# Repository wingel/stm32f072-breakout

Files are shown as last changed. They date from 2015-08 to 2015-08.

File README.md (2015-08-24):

STM32F072 Breakout Board
========================

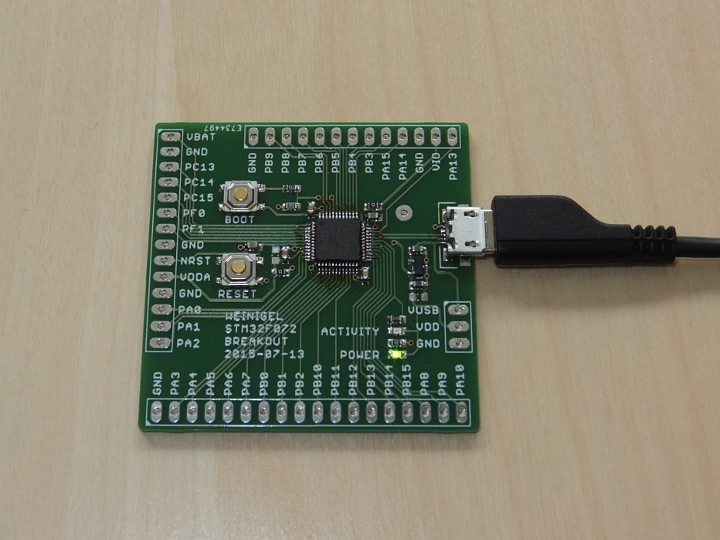
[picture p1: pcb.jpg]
Mounted PCB


This is a small breakout board for the STM32F072 MCU in a LQFP48
package.  I wanted something that would make it easier to try things
out with a small STM2F07 MCU and this PCB is the result.  This PCB
should also work with the STM32F042 MCU and maybe even other STM MCUs
in the same package, but I have not tested that.

Features
--------

* A Micro USB for powering the board and communicating with a host

* All other I/O pins are routed to a 2.54mm pin header

* A voltage regulator which provides VDD

* VIO and VDDA are normally provided from VDD via 0Ω resistors, but
  can optionally be provided externally via a pin header

* RESET and BOOT buttons

* A power LED which shows when the PCB is powered

* A user programmable LED which is connected to I/O pin PA10 (optional)

* PCB is 2 layers and smaller than 50x50mm and so ordering from China
  will only cost about $10 + shipping for 10 PCBs.

Firmware
========

A firmware based on [ChibiOS-RT](http://www.chibios.org/) can be found
on [GitHub](https://github.com/wingel/chibios-stm).

License
=======

[stm32f072-breakout](https://github.com/wingel/stm32f072-breakout) by
[Christer Weinigel](mailto:christer@weinigel.se) is licensed under a
[Creative Commons Attribution 4.0 International
License](http://creativecommons.org/licenses/by/4.0/).



The intent is to make this PCB available to anyone that finds it
useful as long as I get credit for the original design.  If you want
to use the design and have issues with the above license, please
contact me.

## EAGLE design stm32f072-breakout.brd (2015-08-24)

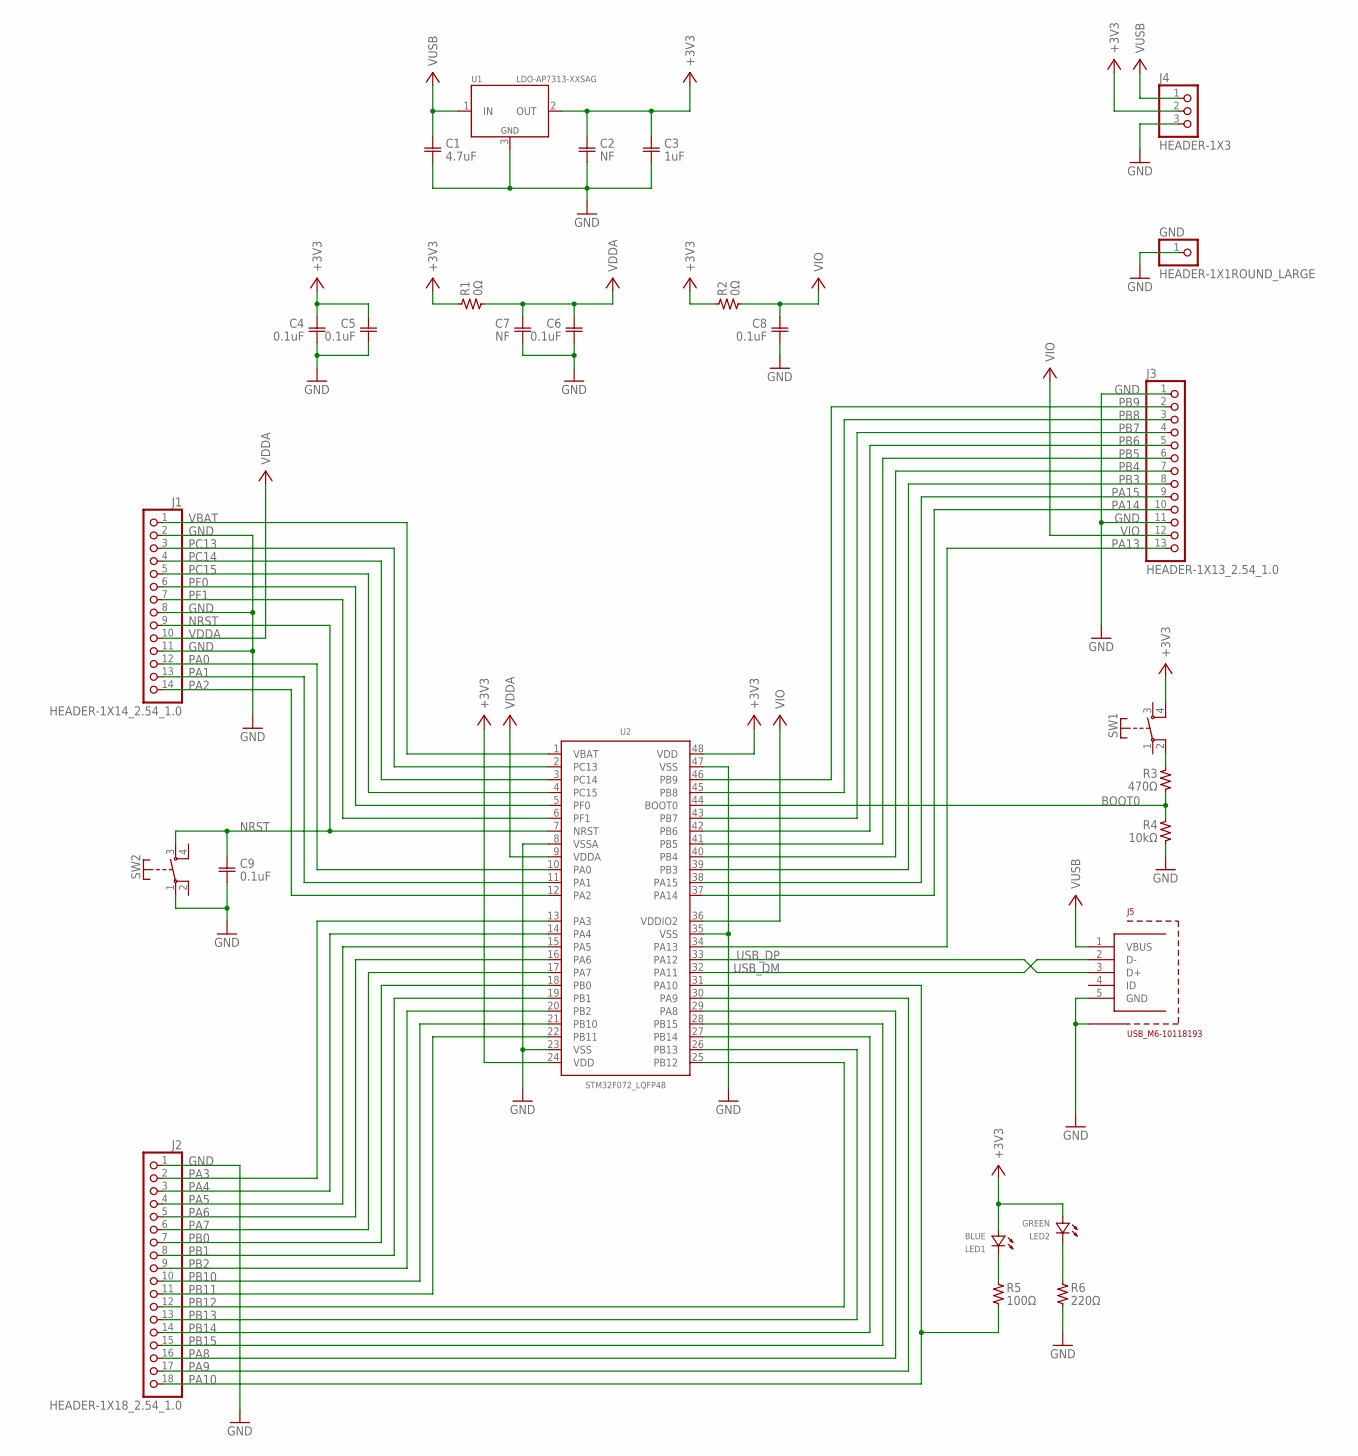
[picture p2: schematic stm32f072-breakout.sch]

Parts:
C1: 4.7uF; 0603
C2, C7: NF; 0603
C3: 1uF; 0603
C4, C5, C6, C8, C9: 0.1uF; 0603
GND: HEADER-1X1ROUND_LARGE; 1X01_ROUND_LARGE
J1: HEADER-1X14_2.54_1.0; 1X14_OVAL
J2: HEADER-1X18_2.54_1.0; 1X18_OVAL
J3: HEADER-1X13_2.54_1.0; 1X13_OVAL
J4: HEADER-1X3; 1X03_OVAL
J5: USB_M6-10118193; FCI-10118193
LED1: BLUE; 0603-POL
LED2: GREEN; 0603-POL
R1, R2: 0Ω; 0603
R3: 470Ω; 0603
R4: 10kΩ; 0603
R5: 100Ω; 0603
R6: 220Ω; 0603
SW1, SW2: SWITCH_OFF(ON)_2-MJTP1140A; MJTP1140A
U1: LDO-AP7313-XXSAG; SOT23
U2: STM32F072_LQFP48; LQFP48

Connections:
+3V3: C2.1, C3.1, C4.1, C5.1, J4.2, LED1.2 (A), LED2.2 (A), R1.1, R2.1, SW1.4, U1.2 (OUT), U2.24 (VDD), U2.48 (VDD)
BOOT0: R3.2, R4.1, U2.44 (BOOT0)
GND: C1.2, C2.2, C3.2, C4.2, C5.2, C6.2, C7.2, C8.2, C9.2, GND.1, J1.2, J1.8, J1.11, J2.1, J3.1, J3.11, J4.3, J5.5 (GND), J5.SHIELD@1 (SHIELD), J5.SHIELD@2 (SHIELD), J5.SHIELD@3 (SHIELD), J5.SHIELD@4 (SHIELD), J5.SHIELD@5 (SHIELD), J5.SHIELD@6 (SHIELD), J5.SHIELD@7 (SHIELD), J5.SHIELD@8 (SHIELD), R4.2, R6.2, SW2.1, U1.3 (GND), U2.8 (VSSA), U2.23 (VSS), U2.35 (VSS), U2.47 (VSS)
unnamed: R3.1, SW1.2
unnamed: LED1.1 (C), R5.1
unnamed: LED2.1 (C), R6.1
NRST: C9.1, J1.9, SW2.3, U2.7 (NRST)
PA0: J1.12, U2.10 (PA0)
PA1: J1.13, U2.11 (PA1)
PA2: J1.14, U2.12 (PA2)
PA3: J2.2, U2.13 (PA3)
PA4: J2.3, U2.14 (PA4)
PA5: J2.4, U2.15 (PA5)
PA6: J2.5, U2.16 (PA6)
PA7: J2.6, U2.17 (PA7)
PA8: J2.16, U2.29 (PA8)
PA9: J2.17, U2.30 (PA9)
PA10: J2.18, R5.2, U2.31 (PA10)
PA13: J3.13, U2.34 (PA13)
PA14: J3.10, U2.37 (PA14)
PA15: J3.9, U2.38 (PA15)
PB0: J2.7, U2.18 (PB0)
PB1: J2.8, U2.19 (PB1)
PB2: J2.9, U2.20 (PB2)
PB3: J3.8, U2.39 (PB3)
PB4: J3.7, U2.40 (PB4)
PB5: J3.6, U2.41 (PB5)
PB6: J3.5, U2.42 (PB6)
PB7: J3.4, U2.43 (PB7)
PB8: J3.3, U2.45 (PB8)
PB9: J3.2, U2.46 (PB9)
PB10: J2.10, U2.21 (PB10)
PB11: J2.11, U2.22 (PB11)
PB12: J2.12, U2.25 (PB12)
PB13: J2.13, U2.26 (PB13)
PB14: J2.14, U2.27 (PB14)
PB15: J2.15, U2.28 (PB15)
PC13: J1.3, U2.2 (PC13)
PC14: J1.4, U2.3 (PC14)
PC15: J1.5, U2.4 (PC15)
PF0: J1.6, U2.5 (PF0)
PF1: J1.7, U2.6 (PF1)
USB_DM: J5.2 (D-), U2.32 (PA11)
USB_DP: J5.3 (D+), U2.33 (PA12)
VBAT: J1.1, U2.1 (VBAT)
VDDA: C6.1, C7.1, J1.10, R1.2, U2.9 (VDDA)
VIO: C8.1, J3.12, R2.2, U2.36 (VDDIO2)
VUSB: C1.1, J4.1, J5.1 (VBUS), U1.1 (IN)

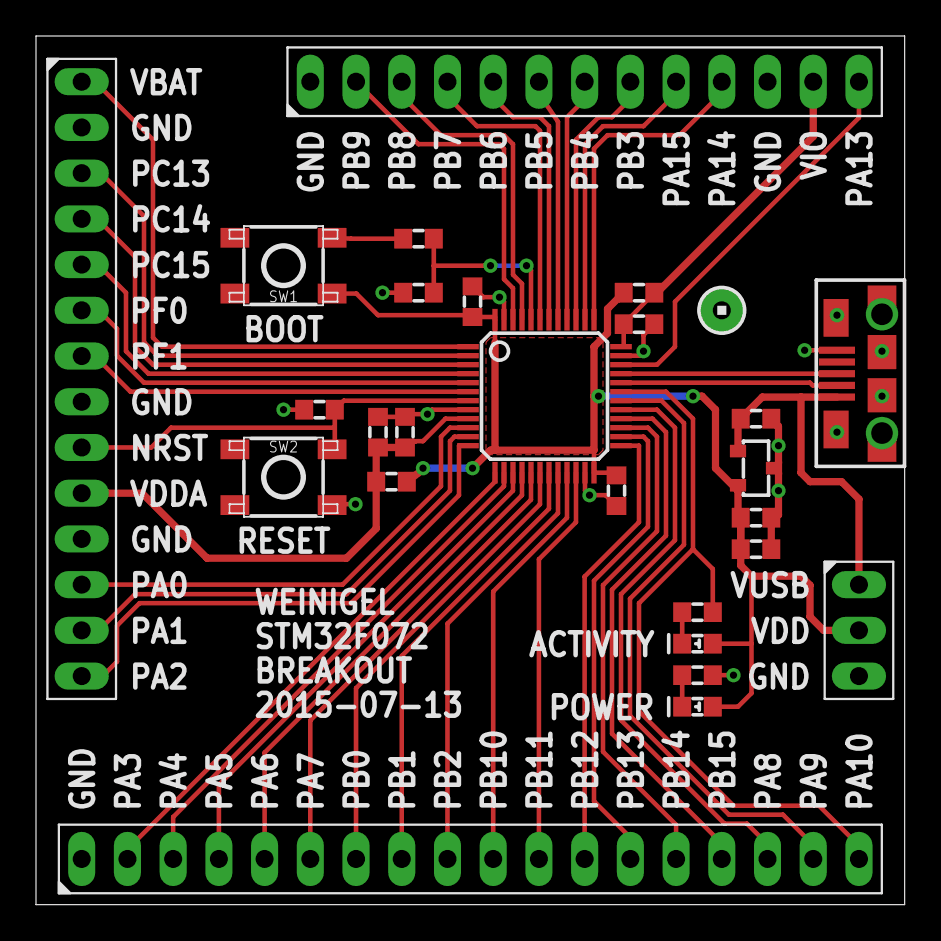
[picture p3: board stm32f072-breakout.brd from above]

Board: 2 copper layers, 48.3 x 48.3 mm, 27 parts (0 on the bottom side), 48 nets.

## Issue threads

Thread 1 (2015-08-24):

Add mounting holes

wingel, 2015-08-24:
In the next version, add 3.5mm mounting holes near the corners.

The holes should preferably be placed using the same 2.54mm grid as the pin headers.

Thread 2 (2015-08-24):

Replace push buttons with jumpers

wingel, 2015-08-24:
The push buttons are convenient for a product, but I have realized that having jumpers is actually better, that way the MCU can boot into USB DFU mode on every reset instead of having to fiddle with pushing buttons.

Or if space allows, add jumpers in addition to the buttons.

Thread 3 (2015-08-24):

Add CR2032 battery holder

wingel, 2015-08-24:
Add a footprint for a CR2032 battery holder to the back of the PCB and connect + from the battery to VBAT.  This would allow me to keep a RTC running at all times even when the board is not powered.

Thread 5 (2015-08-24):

Change voltage regulator U1 footprint

wingel, 2015-08-24:
The footprint I have chosen for the voltage regulator (Diodes AP7313) is a rather uncommon one.  Switch to a more common footprint such as the Diodes AP7313-R or Microchip MCP1700.
